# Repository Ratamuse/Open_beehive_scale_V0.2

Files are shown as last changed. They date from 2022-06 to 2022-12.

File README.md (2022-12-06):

# Open_beehive_scale_V0.2

Balance connectée autonome sur réseau LORA/LORAWAN

1/Exemple de balance en profilé alu de type Bosch Rexroth utilisable sur fond de ruche Nicot.

- 2x profilé alu 60x30mm fente 8mm de 480mm
- 4 x profilé alu 30x30mm fente 8mm de 430mm
- 1 jauge de contrainte BOSCHE H40A de 150 kg
- 24 x equerre de fixation interne profilés 8 mm

Pièces imprimées 3D

- 4 x capuchons pour profilés du bas de la balance.
- 2 x capuchons arrière pour maintenir le fond de ruche Nicot.
- 1 x capuchon gauche et 1 x capuchon droit pour maintenir le fond de ruche Nicot.
- 2 x entretoises à placer entre les profilés 60x30 et la jauge de contrainte.
- 8 x vis tête cylindrique bombée M8x40mm
- 4 x vis tête cylindrique bombée M8x30mm

Prévoir un taraud M5 pour fileter de chaque coté deux profilés alu 30x30mm

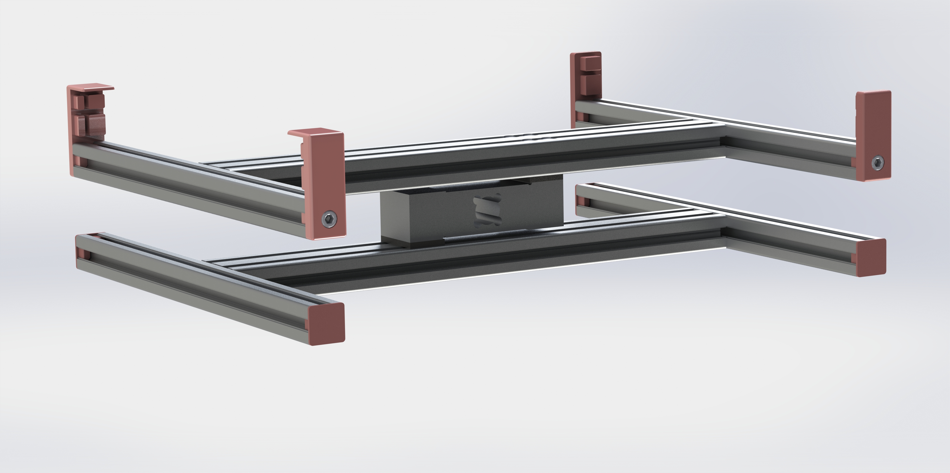
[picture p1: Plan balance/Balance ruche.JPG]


2/ Circuit imprimé dessiné autour de la carte Arduino MKRWAN 1310
- Possibilité de brancher jusqu'à:
- 4 balances (circuit HX711)
- 4 sondes externes de température/humidité SHT40
- 4 sondes de température DS1820b
- 1 broche I2C spare (possibilité de brancher par exemple un capteur de luminosité)
- 1 broche analogique ou numérique spare (possibilité de brancher par exemple un pluviomètre)
- 1 GPS QUECTEL L80-M33
- 1 batterie Lipo
- 1 panneau solaire 1W

Recharge de la batterie par un chargeur solaire MPPT. 
Surveillance de la température/humidité de la carte par un capteur SHT4X soudé sur la carte.
Jauge batterie I2C
Baromètre MS5611
Lecteur de carte SD
Capteur de mouvement (contacteur à bille) pour créer un alarme.

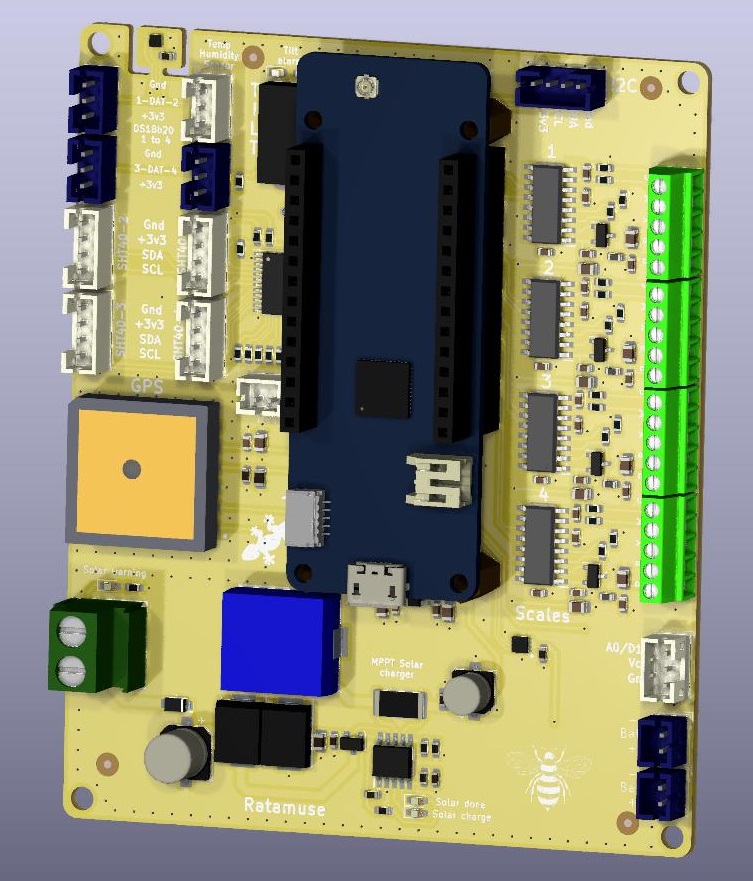
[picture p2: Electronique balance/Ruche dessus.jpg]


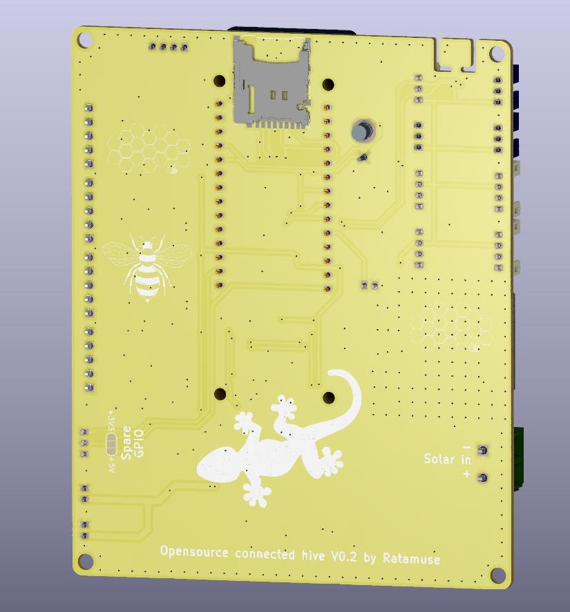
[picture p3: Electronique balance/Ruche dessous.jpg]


3/Récupération des données: 

Les données sont envoyées sur The Things Network via une passerelle Lora situé dans mon logement.
Les données sont ensuites récupérées sur un raspberry et affichées soit sur Domoticz soit sur Grafana via la création de bases de données InfluxDB et récupération des données avec NodeRed. 

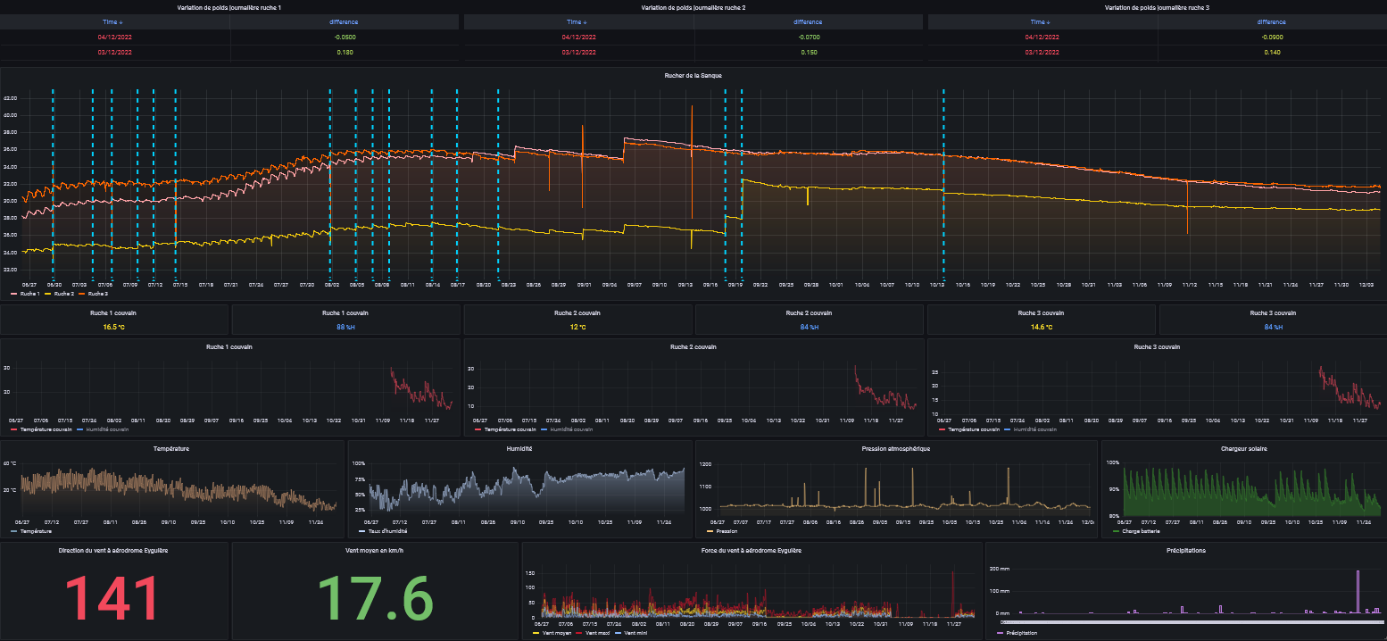
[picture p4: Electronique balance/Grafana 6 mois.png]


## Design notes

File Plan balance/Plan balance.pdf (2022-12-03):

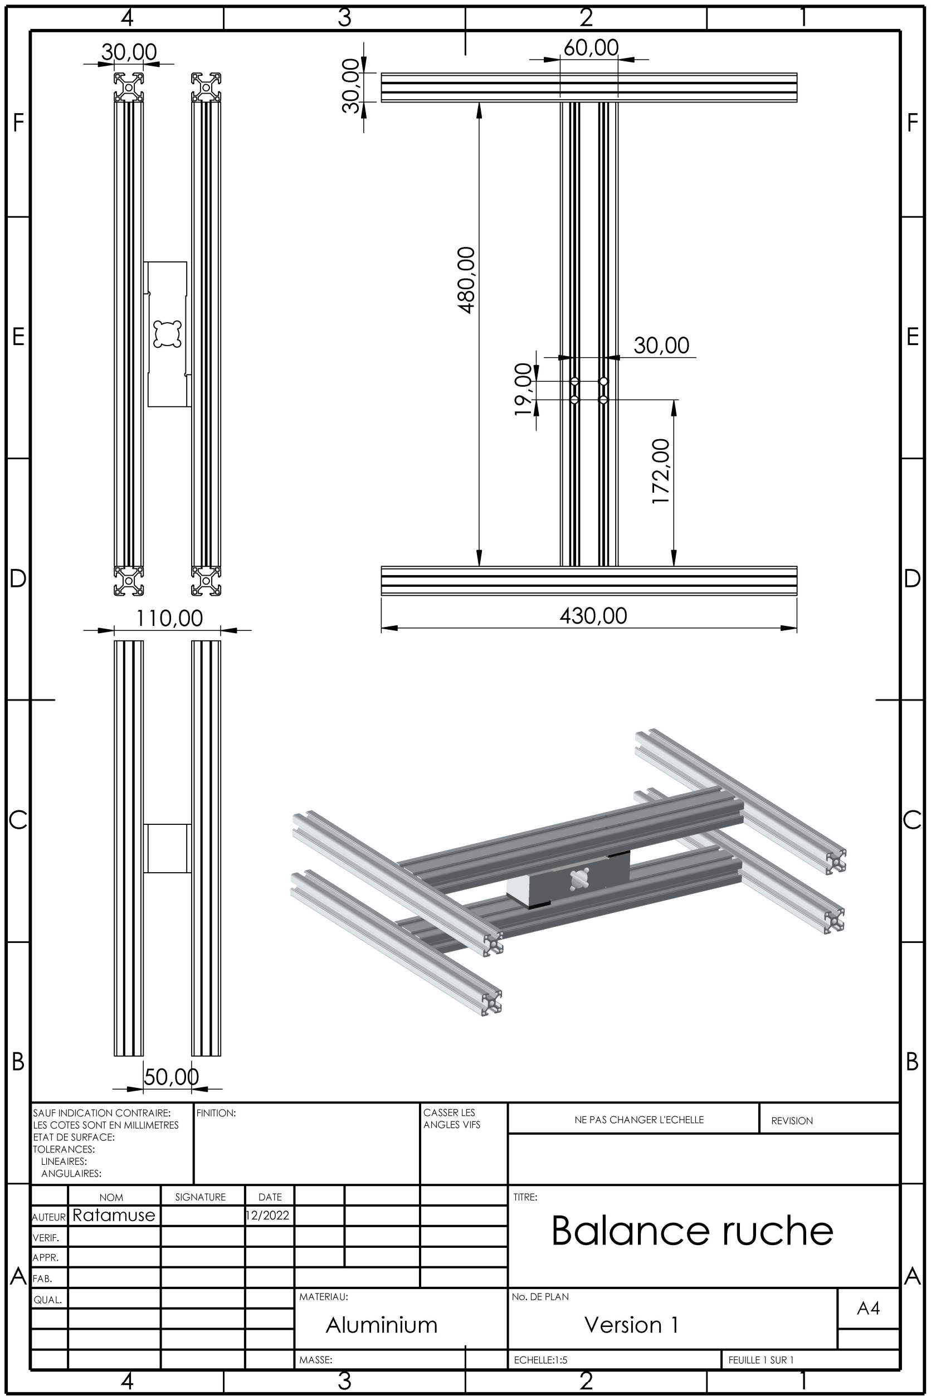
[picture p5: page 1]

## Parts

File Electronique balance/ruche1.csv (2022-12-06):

Id | Référence | Boîtier | Quantité | Désignation | Fournisseur et réf
1 | C1 | CP_Elec_6.3x7.7 | 1 | 100µF/35V
2 | C2 | C_0603_1608Metric | 1 | 470nF/50V
3 | C3 | C_0805_2012Metric | 1 | 4.7µF/50V
4 | C4 | C_0603_1608Metric | 1 | 220nF
5 | C5,C6,C20,C38,C41,C33,C29,C22,C36,C40,C48,C15,C34,C19,C28,C31,C53,C47,C26,C14,C25,C32,C43,C50,C24,C45,C10,C39,C17,C46 | C_0603_1608Metric | 30 | 0.1µF
6 | C7 | C_0603_1608Metric | 1 | 0.1µF/50V
7 | C8,C11,C18,C23,C44,C30,C35,C49,C12,C27,C42,C54,C13,C16,C37 | C_0805_2012Metric | 15 | 10µF
8 | C9 | CP_Elec_5x5.4 | 1 | 10µF
9 | D1,D3,D4 | LED_0603_1608Metric_Castellated | 3 | LED
10 | D2 | SODFL3616X98N | 1 | MBR230LSFT1G
11 | D5,D6 | DIOM8059X256N | 2 | SS34
12 | IC1 | SOP100P600X175-10N | 1 | CN3791
13 | J1 | SHDR2W90P0X500_1X2_1060X980X1380P | 1 | Conn_01x02
14 | J5,J11,J12,J17,J18 | JST_PH_B4B-PH-K_1x04_P2.00mm_Vertical | 5 | Conn_01x04
15 | L1 | INDPM138126X700N | 1 | 82µH/3A
16 | Q1 | SOT-23 | 1 | AO3401A
17 | R1 | R_0603_1608Metric | 1 | 2K
18 | R2 | R_0603_1608Metric | 1 | 120
19 | R3,R4,R7,R8,R32,R40,R38,R36,R39,R11,R34,R37,R33,R35 | R_0603_1608Metric | 14 | 10K
20 | R5 | R_0603_1608Metric | 1 | 30K
21 | R6 | R_2512_6332Metric | 1 | 0.24R
22 | J6,J7,J19 | JST_PH_B2B-PH-K_1x02_P2.00mm_Vertical | 3 | Conn_01x02
23 | IC2 | SON50P200X200X80-9N-D | 1 | MAX17048G+
24 | J8,J9,J3,J14,J4 | JST_PH_B3B-PH-K_1x03_P2.00mm_Vertical | 5 | Conn_01x03
25 | IC3 | L80-M39 | 1 | L86-M33
26 | R10 | R_0603_1608Metric | 1 | 100k
27 | S1 | RB231X2 | 1 | RB231X2
28 | R17,R29,R25,R21 | R_0603_1608Metric | 4 | 8.2K
29 | C52 | C_0805_2012Metric | 1 | 0.1µF
30 | Q5,Q3,Q4,Q2 | SOT-23 | 4 | MMBT4403
31 | C51 | C_0603_1608Metric | 1 | 10µF
32 | R16,R28,R20,R24 | R_0603_1608Metric | 4 | 20K
33 | J16,J2,J10,J15 | connecteurs5 | 4 | Conn_01x05
34 | L4,L2,L5,L3 | L_0603_1608Metric | 4 | 3.3µH
35 | D7 | LED_0603_1608Metric | 1 | LED
36 | U4 | TSSOP-24_4.4x7.8mm_P0.65mm | 1 | TCA9548APWR
37 | U5,U3 | SOT-23-5 | 2 | XC6220B331MR
38 | FB1 | R_0603_1608Metric | 1 | FerriteBead
39 | C21 | C_0805_2012Metric | 1 | 4.7µF
40 | R27,R30,R26,R22,R31,R19,R18,R23 | R_0603_1608Metric | 8 | 100
41 | IC6,IC7,IC8,IC5 | SOIC127P600X160-16N | 4 | HX711
42 | R15,R14,R13 | R_0603_1608Metric | 3 | 10k
43 | U1 | ARDUINO_ABX00012 | 1 | MKRWAN_1310
44 | G*** | Logo Ratamuse petit | 1 | LOGO
45 | FID4,FID1,FID2,FID3 | Fiducial_1mm_Mask3mm | 4 | Fiducial
46 | IC4 | SHT41AD1BR3 | 1 | SHT41-AD1B-R3
47 | R9 | R_0603_1608Metric | 1 | 4.7K
48 | U2 | LGA-8_3x5mm_P1.25mm | 1 | MS5611-01BA
49 | JP1 | SolderJumper-3_P1.3mm_Open_RoundedPad1.0x1.5mm_NumberLabels | 1 | SolderJumper_3_Open
50 | J13 | microSD_HC_Hirose_DM3AT-SF-PEJM5 | 1 | Micro_SD_Card
51 | G*** | Logo Ratamuse | 1 | LOGO

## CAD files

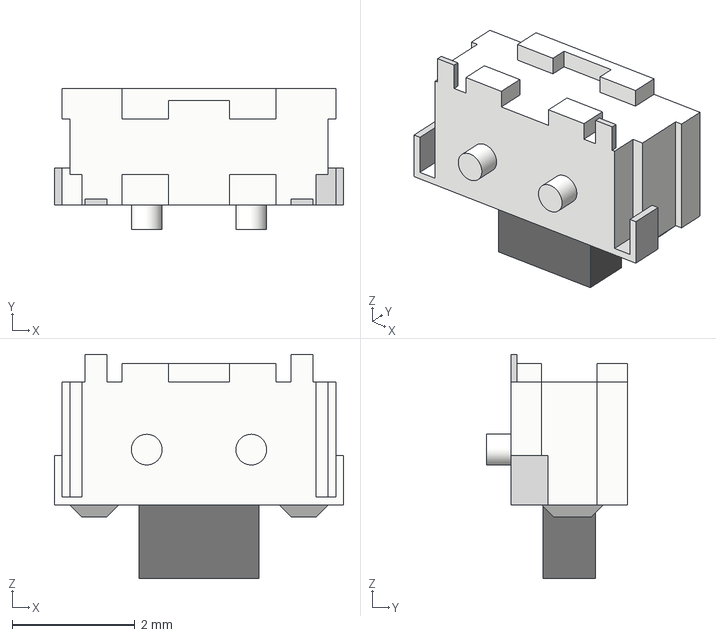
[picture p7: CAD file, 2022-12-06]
Electronique balance/3D/1TS003B.step
4.70 x 2.30 x 3.65 mm

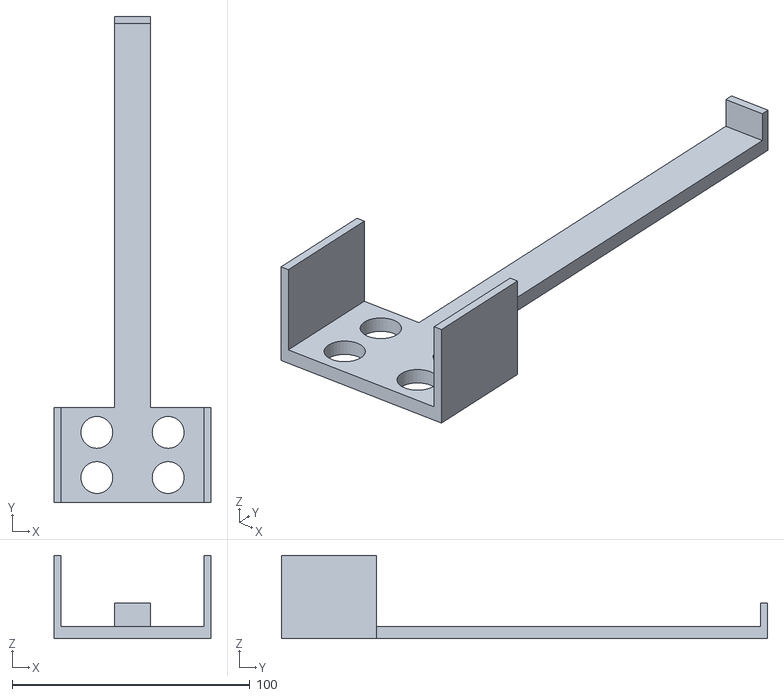
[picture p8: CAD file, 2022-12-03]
Plan balance/gabarit percage ruche13.STL
66.0 x 204.5 x 35.0

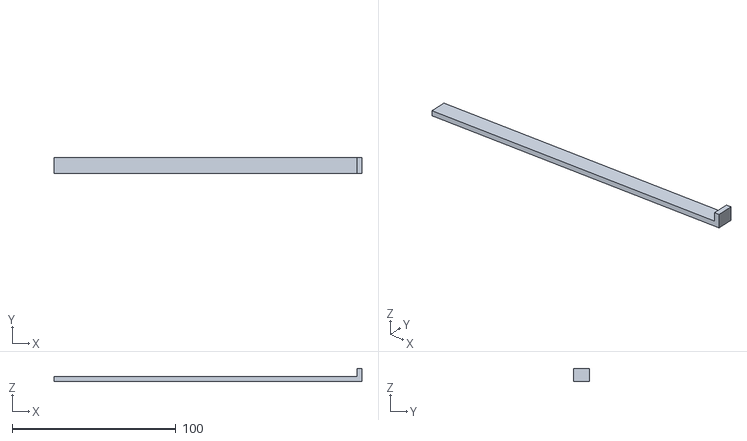
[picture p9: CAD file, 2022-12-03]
Plan balance/gabari placement bras balance.STL
188.0 x 10.0 x 8.00

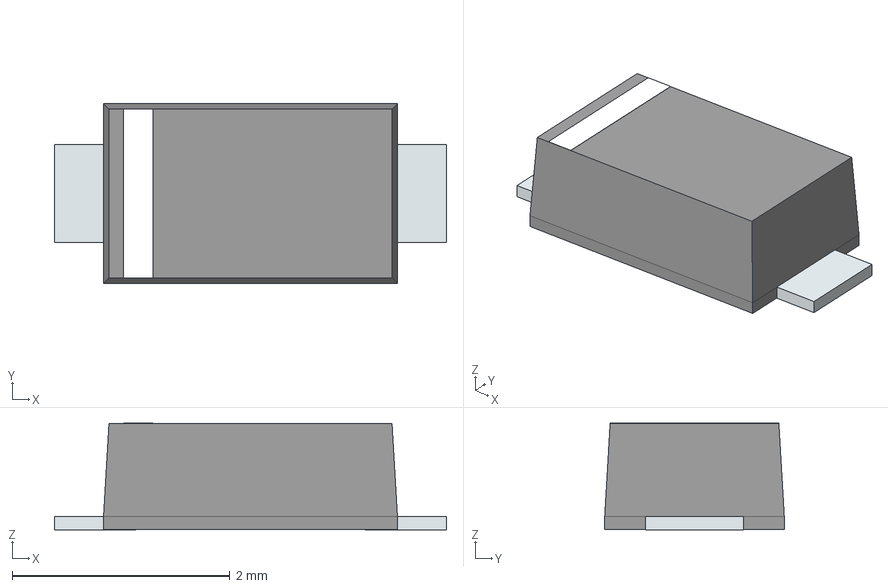
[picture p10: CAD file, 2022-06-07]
Electronique balance/3D/MBR230LSFT1G.stp
3.60 x 1.65 x 0.98 mm
PinKIdent
PinK
PinA

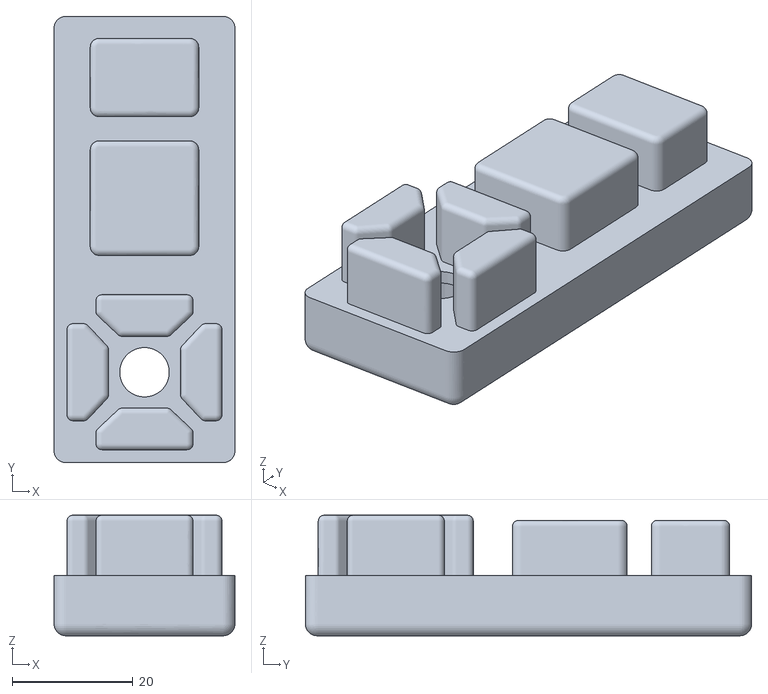
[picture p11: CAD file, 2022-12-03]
Plan balance/Fixation plancher Nicot AR.STL
30.0 x 74.0 x 20.0

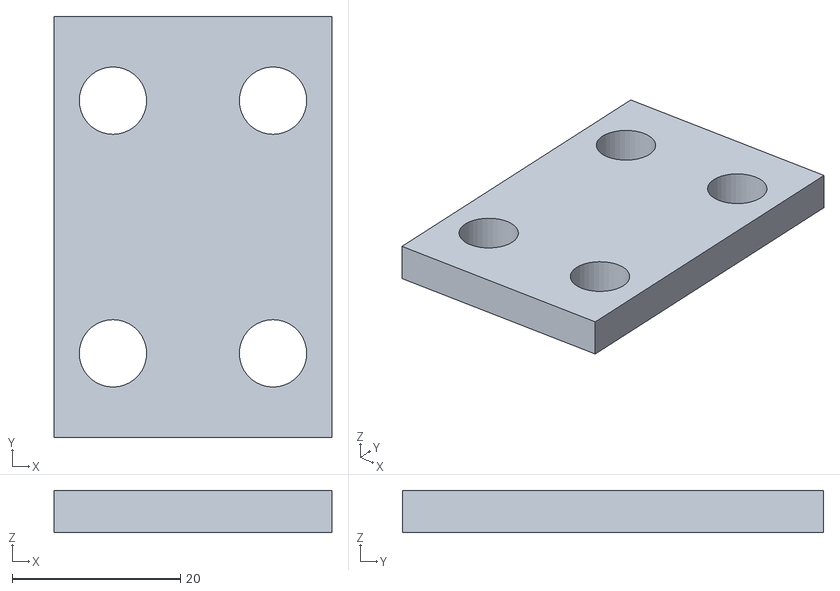
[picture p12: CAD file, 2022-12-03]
Plan balance/Entretoise balance.STL
33.0 x 50.0 x 5.00

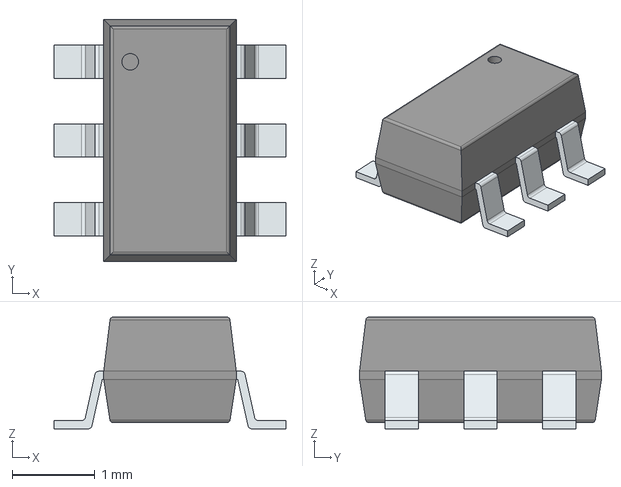
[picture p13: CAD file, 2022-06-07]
Electronique balance/3D/DW01.stp
2.80 x 2.92 x 1.35 mm
PinsArrayLR

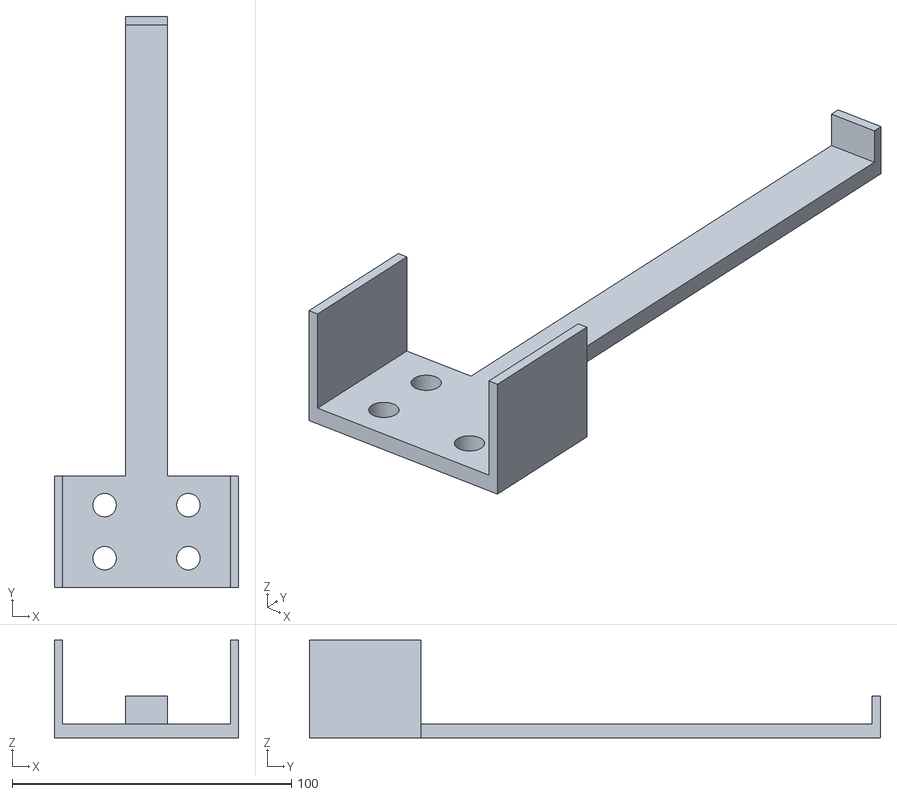
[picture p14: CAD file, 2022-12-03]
Plan balance/gabarit percage ruche.STL
66.0 x 204.5 x 35.0

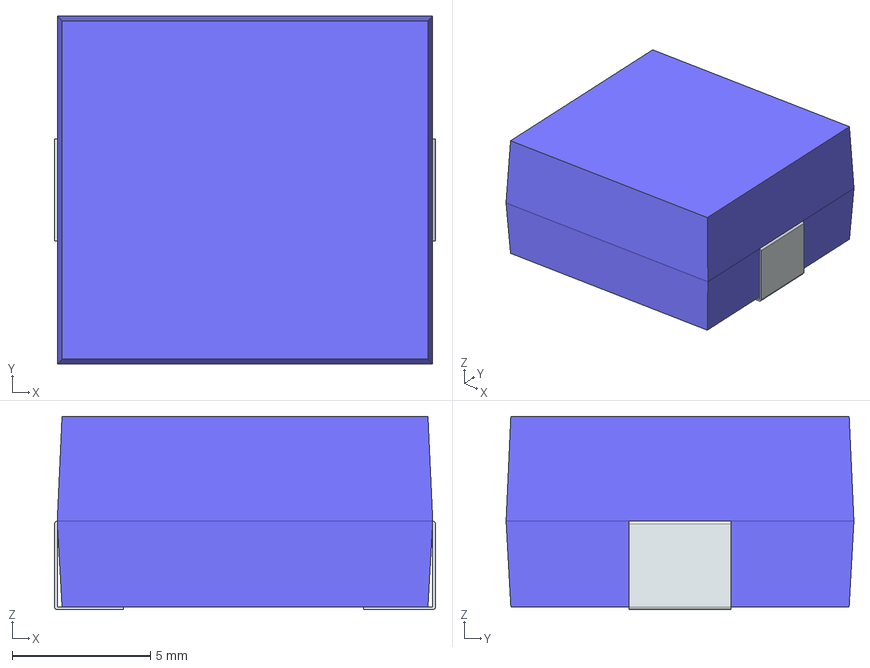
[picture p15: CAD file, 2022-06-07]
Electronique balance/3D/SMMS1360-220M.stp
13.8 x 12.6 x 7.00 mm
FilletPin1
FilletPin2

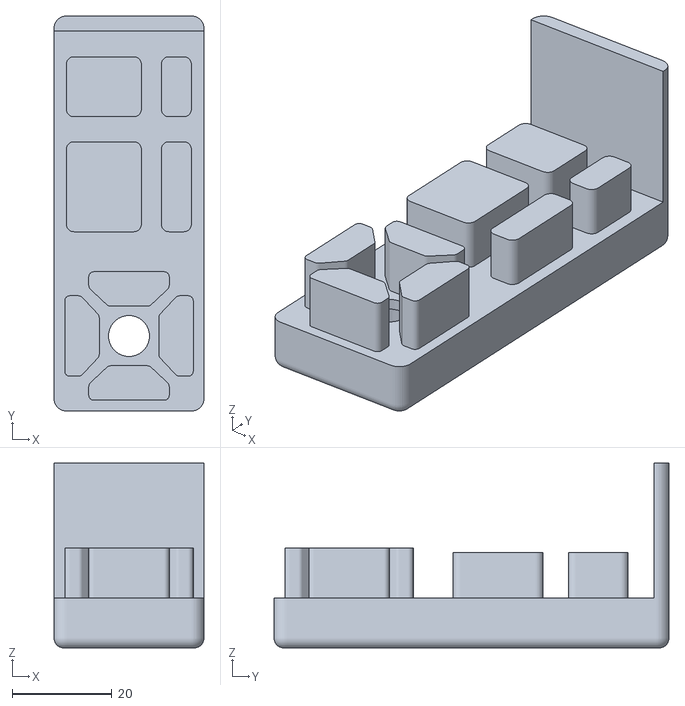
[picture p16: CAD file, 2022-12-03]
Plan balance/Fixation plancher Nicot AV G.STL
30.0 x 79.0 x 37.0

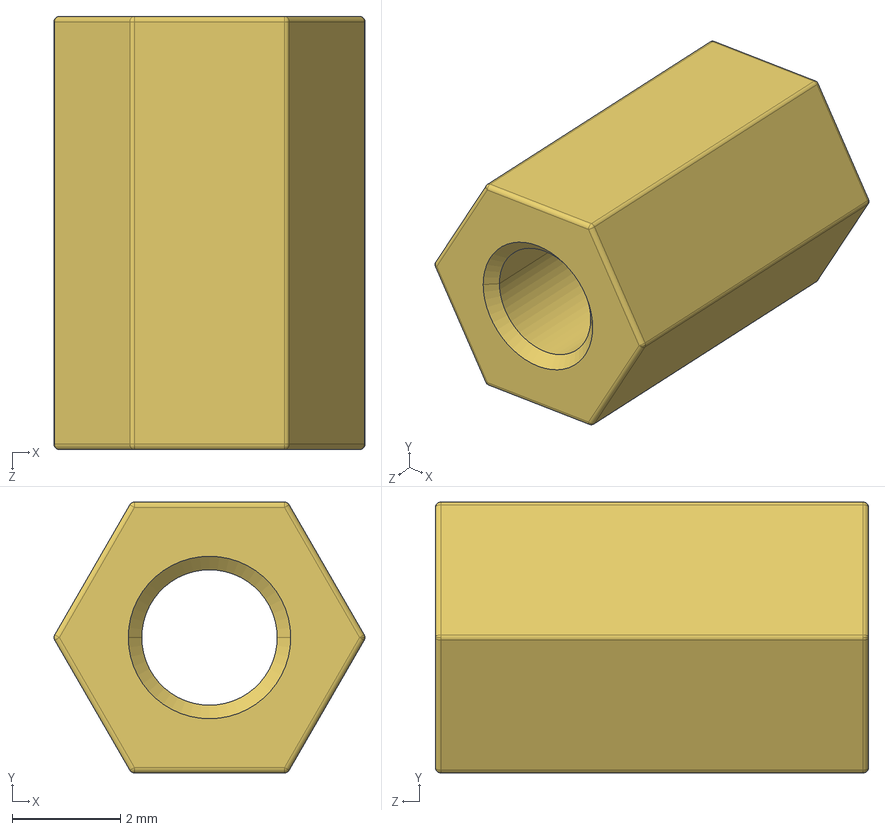
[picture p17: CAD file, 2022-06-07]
Electronique balance/3D/HTSB-M3-8-5-1.STEP
5.74 x 5.00 x 8.00 mm

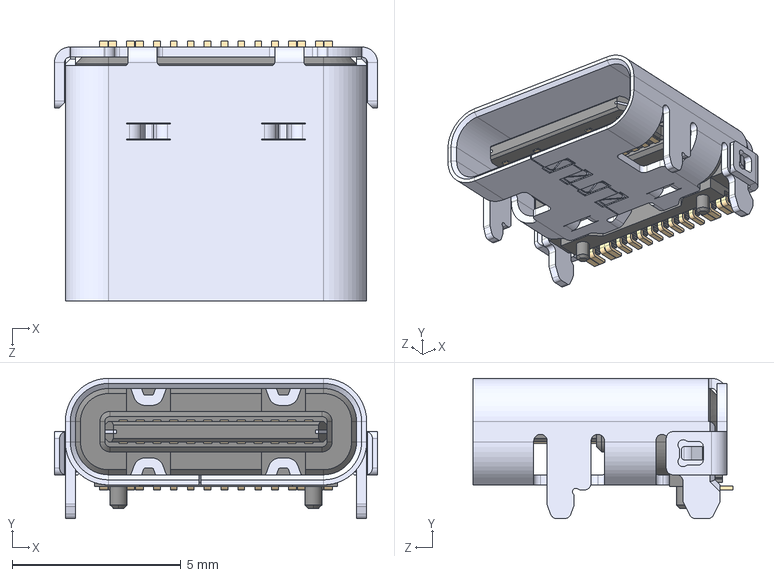
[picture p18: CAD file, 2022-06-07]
Electronique balance/3D/USB4105-GF-A--3DModel-STEP-56544.STEP
9.58 x 4.16 x 7.71 mm

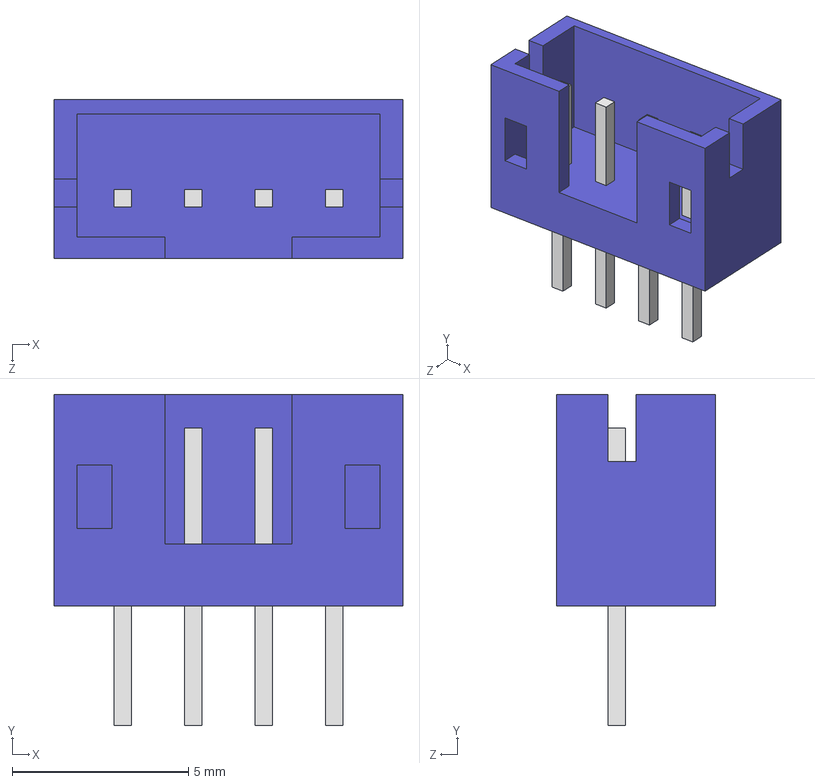
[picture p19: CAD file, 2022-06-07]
Electronique balance/3D/B4B-PH-K-S.STEP
9.90 x 9.40 x 4.50 mm

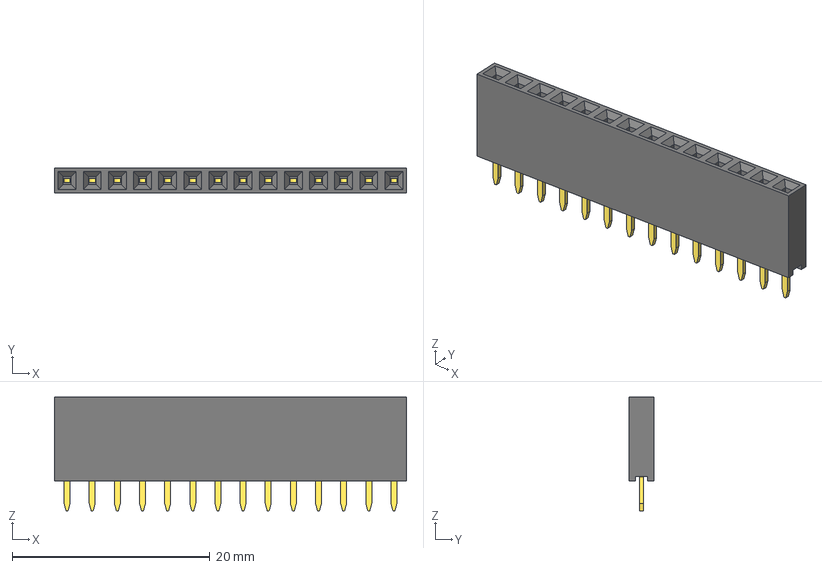
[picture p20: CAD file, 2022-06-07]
Electronique balance/3D/PBS-14.step
35.6 x 2.54 x 11.5 mm

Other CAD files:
Plan balance/Fixation plancher Nicot AV D.STL
Electronique balance/3D/AO3400.stp
Electronique balance/3D/FS8205.stp
Electronique balance/3D/MMBT4403.stp
Electronique balance/3D/1050170001.stp
Electronique balance/3D/12BHC186P1-GR.stp
Electronique balance/3D/1546215-2.stp
Electronique balance/3D/39700-0205.stp
Electronique balance/3D/691216710002.stp
Electronique balance/3D/B2B-PH-K-S.STEP
Electronique balance/3D/B3B-PH-K-S.STEP
Electronique balance/3D/B3S_100[].step
Electronique balance/3D/B4B-PH-SM4-TB.STEP
Electronique balance/3D/BME680.step
Electronique balance/3D/CN3791.stp
Electronique balance/3D/ESP32-WROOM-32E_M113EH2800PH3Q0_.stp
Electronique balance/3D/FS312F-G.stp
Electronique balance/3D/FS8205A.stp
Electronique balance/3D/HTSB-M3-12-5-1.STEP
Electronique balance/3D/HTSB-M3-8-5,5-1.STEP
Electronique balance/3D/HX711.stp
Electronique balance/3D/L86.step
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

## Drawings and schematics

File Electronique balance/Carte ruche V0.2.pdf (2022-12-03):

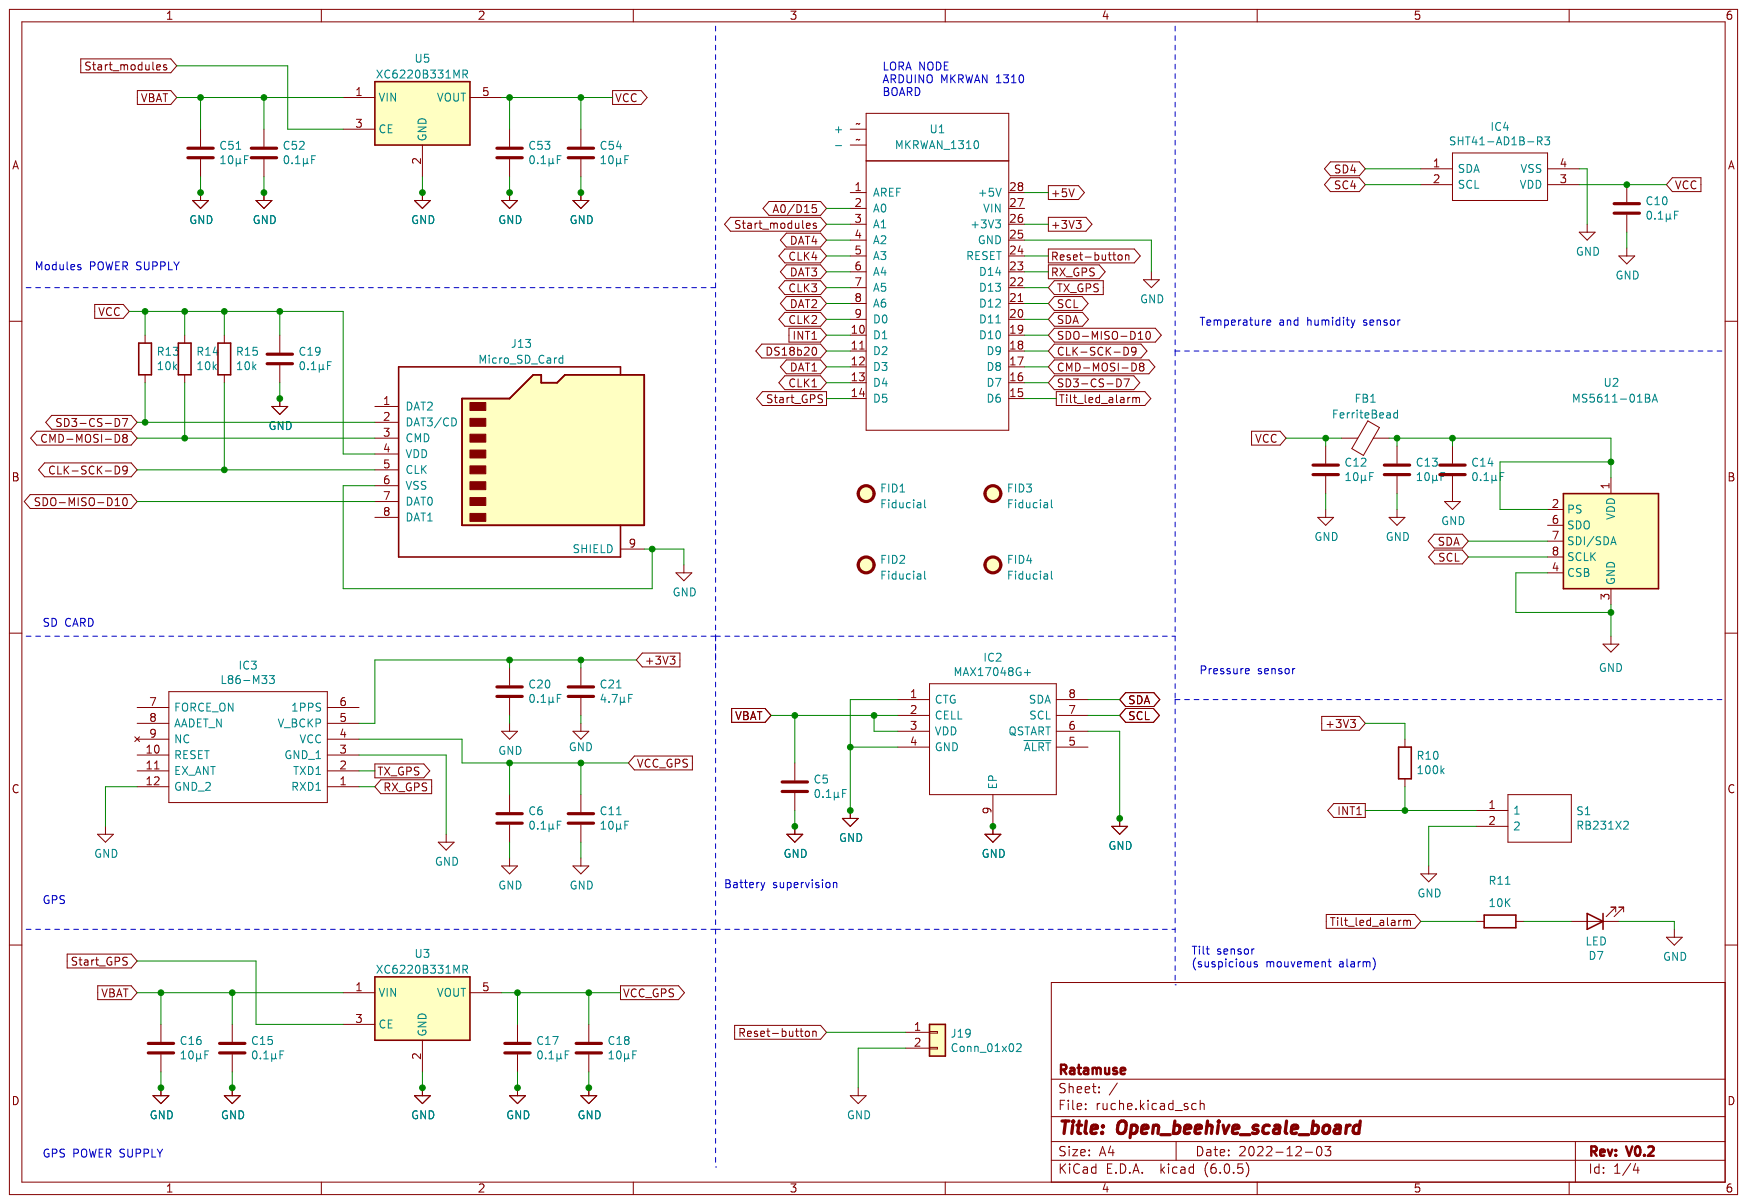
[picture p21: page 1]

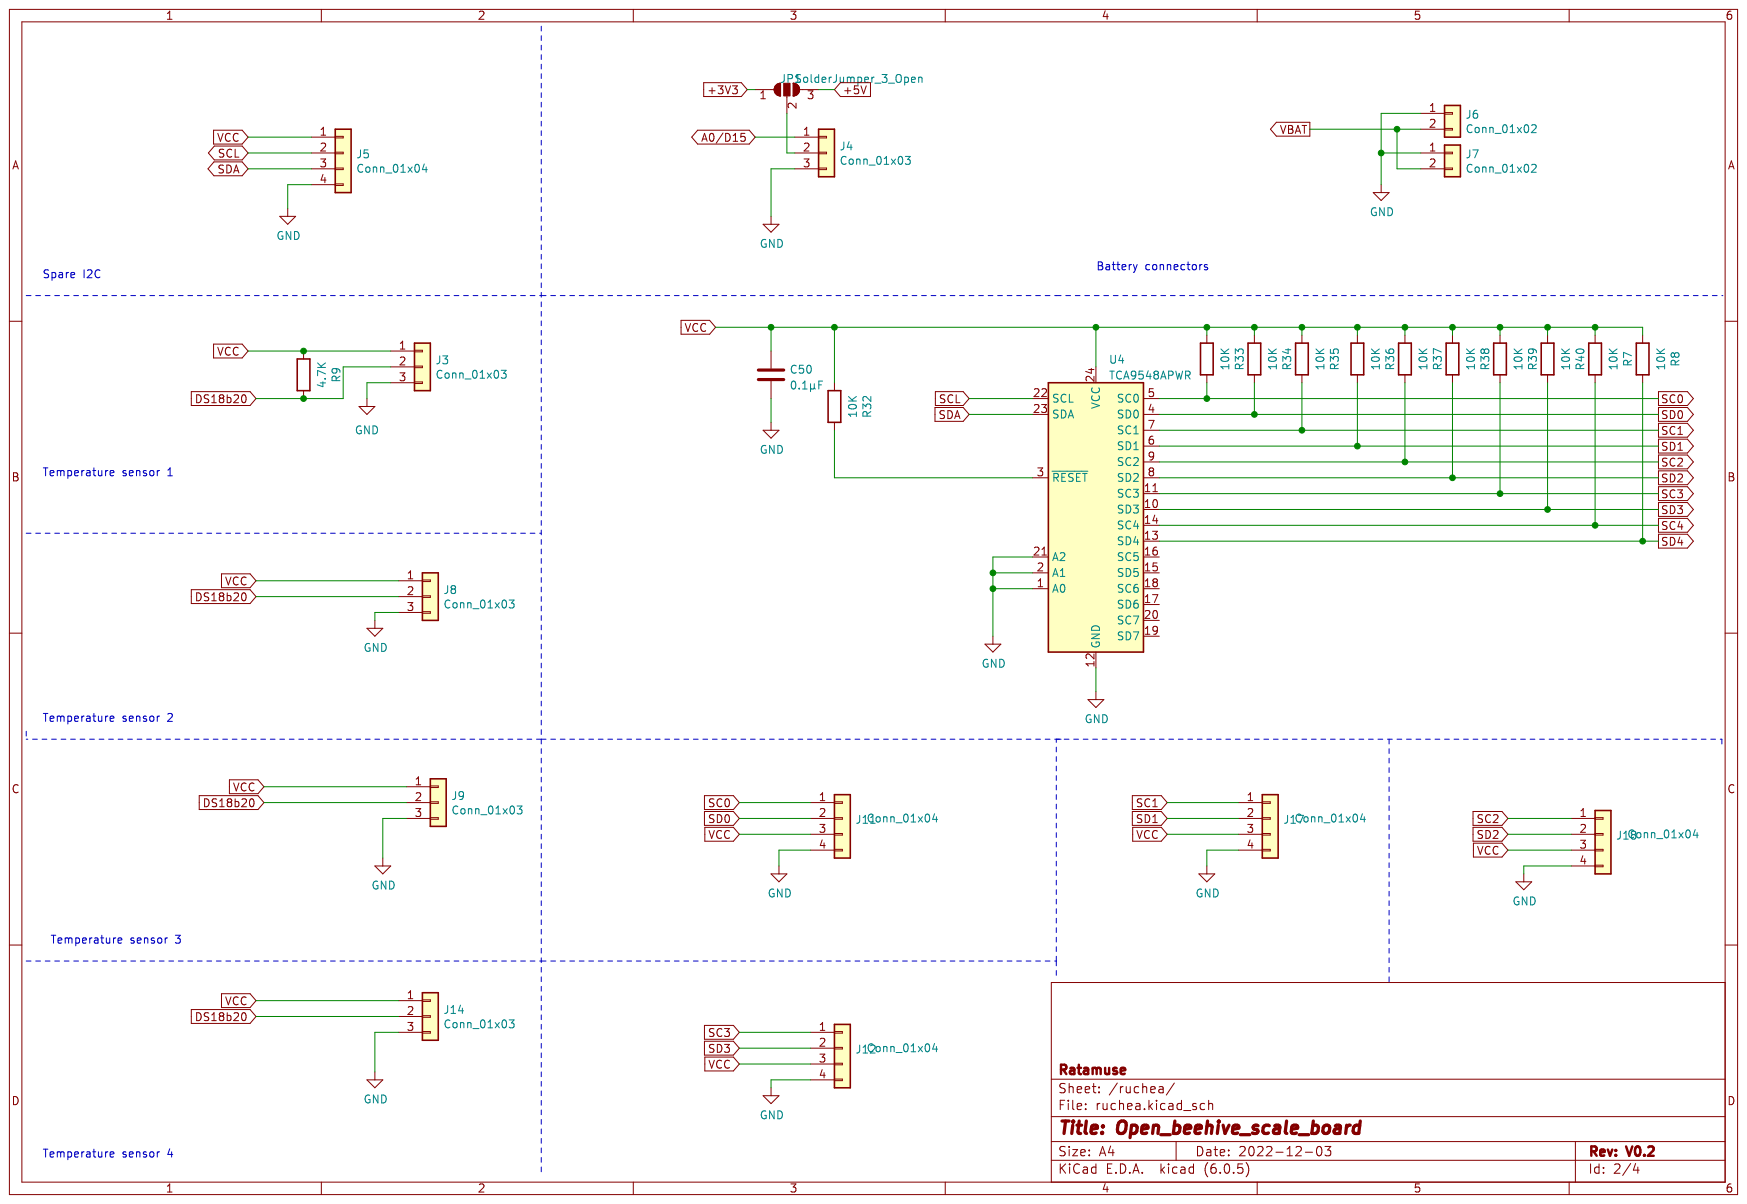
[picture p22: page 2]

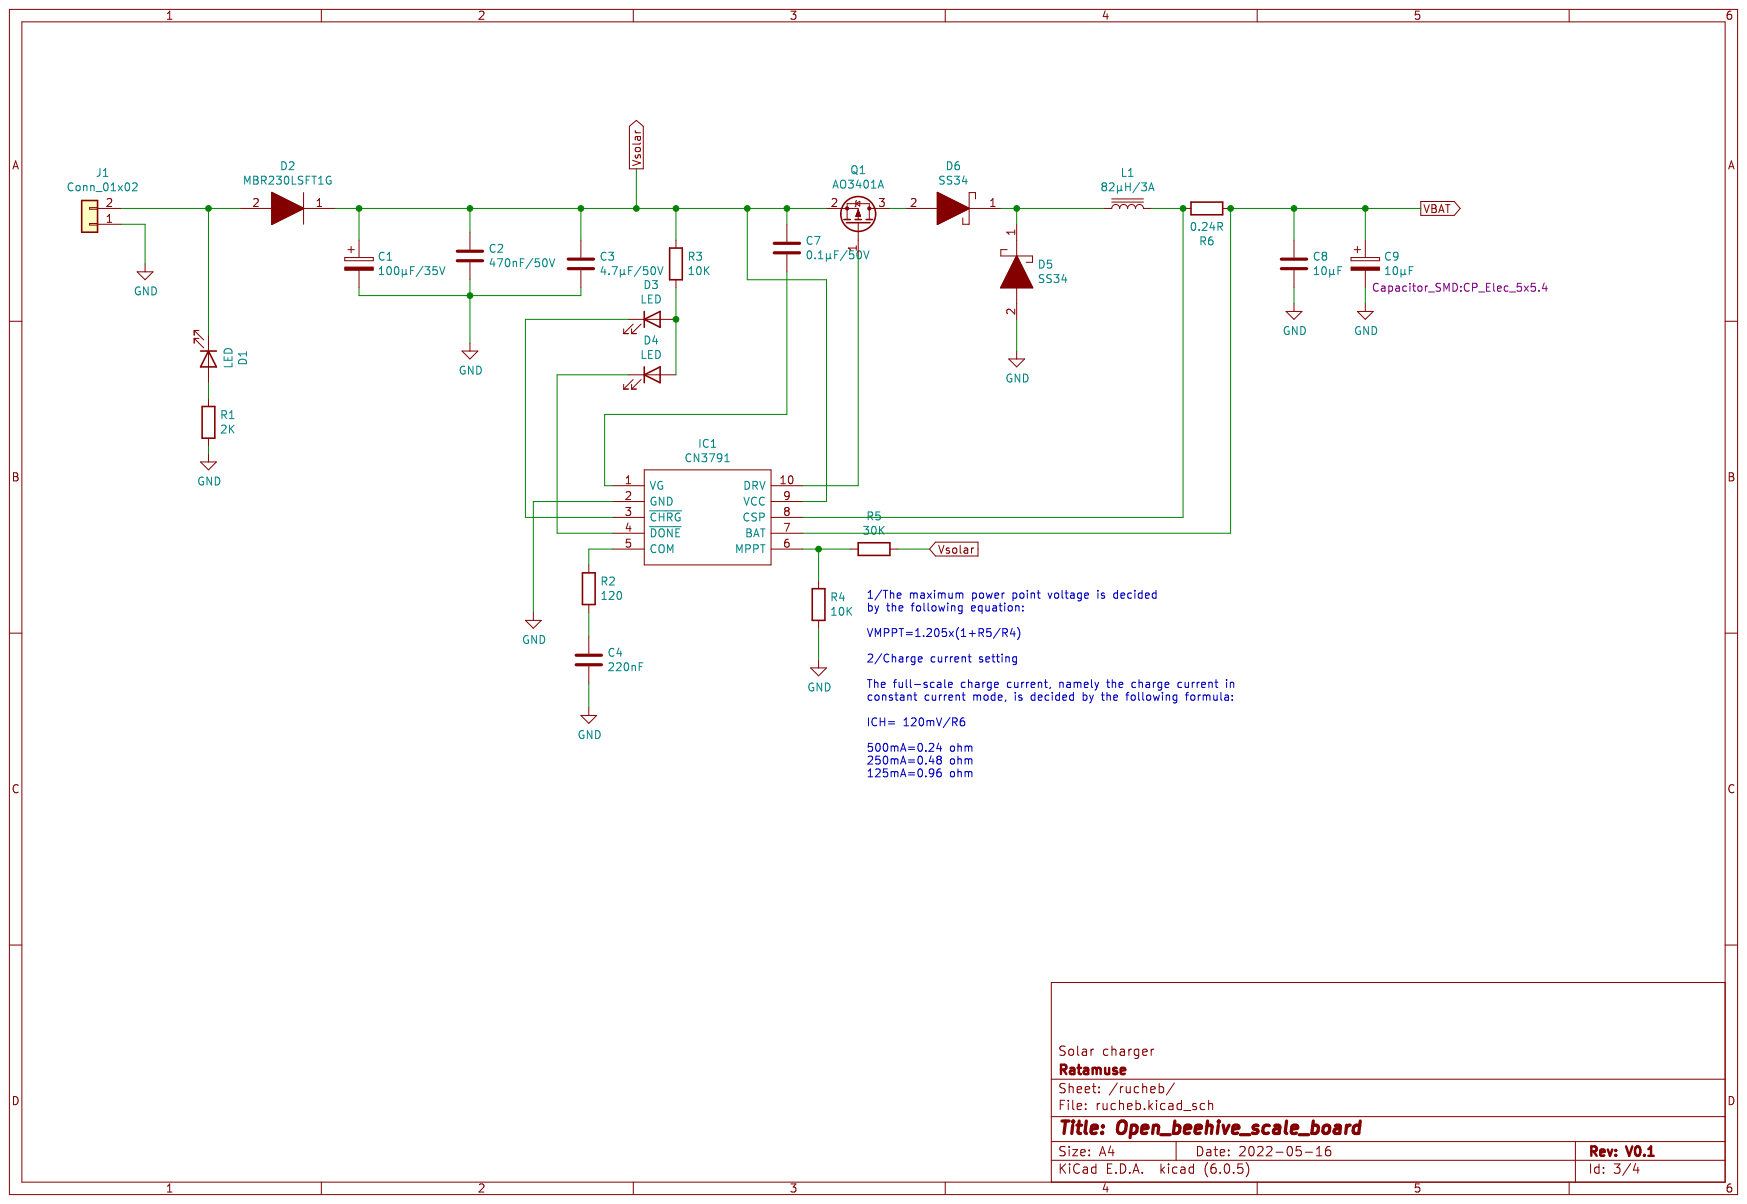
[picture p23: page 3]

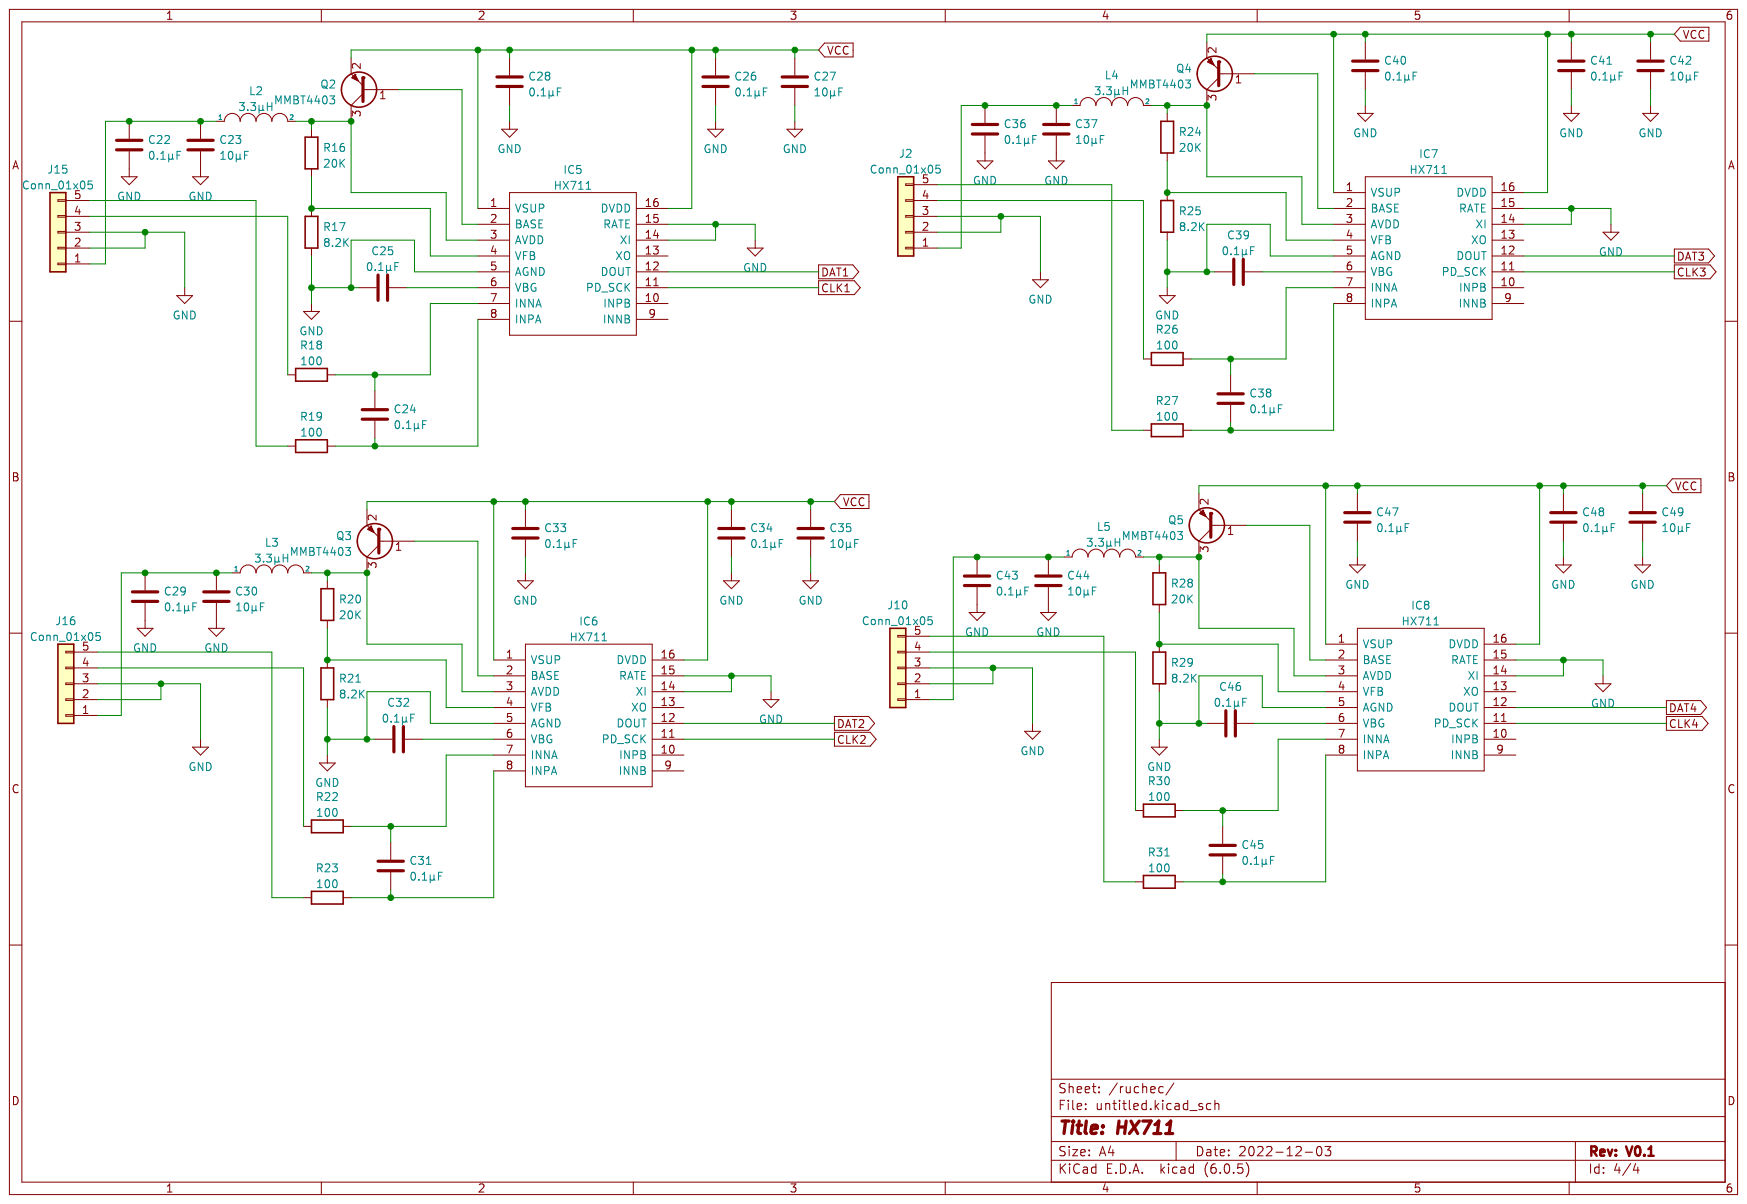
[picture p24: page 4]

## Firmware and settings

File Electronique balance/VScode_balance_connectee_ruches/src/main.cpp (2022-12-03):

#include <MKRWAN.h>           // LoRaWAN Library
#include <CayenneLPP.h>       // CAYENNE LPP
#include "ArduinoLowPower.h"  // Low Power Library




#define FRAME_DELAY       300000
#define DATA_RATE         5
#define ADAPTIVE_DR       true
#define CONFIRMED         false
#define PORT              2
#define CAYENNE_LPP       true
#define LOW_POWER         false
#define DEBUG
//#undef DEBUG

void getWeightscale1();
void getWeightscale2();
void getWeightscale3();
void Max17048();
void SHT4x();
void sendLoRa();
void enterLowPower();




/**** LoRaWAN Setup ******/
LoRaModem modem;
String appEui = "0000000000000000"; 
//String appKey = "xxxxxxxxxxxxxxxxxxxxxx";   // Ruche 1
String appKey = ""xxxxxxxxxxxxxxxxxxxxxx"";   // Ruche 2
uint8_t dataToSend[20] = {0}; // Data to send
uint8_t dataReceived[20] = {0}; // Data received via Donwlink
uint32_t frameDelay = FRAME_DELAY;

CayenneLPP dataToSendCayenne(51);
CayenneLPP dataReceivedCayenne(51);


/*********HX711***************/

#include "HX711.h"


// HX711 circuit wiring
const int LOADCELL_DOUT_PIN1 = 4;
const int LOADCELL_SCK_PIN1 = 3;
const int LOADCELL_DOUT_PIN2 = 18;
const int LOADCELL_SCK_PIN2 = 17;
const int LOADCELL_DOUT_PIN3 = 20;
const int LOADCELL_SCK_PIN3 = 19;

HX711 scale1;
HX711 scale2;
HX711 scale3;

#define number1
void HT711_1(number1);

#define number2
void HT711_2(number2);

#define number3
void HT711_3(number3);

/***************************************DS18B20*********************************/

// Include the libraries we need
#include <OneWire.h>
#include <DallasTemperature.h>

// Data wire is plugged into port 13 on the Arduino
#define ONE_WIRE_BUS 13

// Setup a oneWire instance to communicate with any OneWire devices (not just Maxim/Dallas temperature ICs)
OneWire oneWire(ONE_WIRE_BUS);

// Pass our oneWire reference to Dallas Temperature. 
DallasTemperature sensors(&oneWire);

/*The setup function. We only start the sensors here*/
int deviceCount = 0;
float tempC;

/*************************MAX17048****************************************/

#include <Wire.h> // Needed for I2C
#include <SparkFun_MAX1704x_Fuel_Gauge_Arduino_Library.h> // Click here to get the library: http://librarymanager/All#SparkFun_MAX1704x_Fuel_Gauge_Arduino_Library

//SFE_MAX1704X lipo; // Defaults to the MAX17043

//SFE_MAX1704X lipo(MAX1704X_MAX17043); // Create a MAX17043
//SFE_MAX1704X lipo(MAX1704X_MAX17044); // Create a MAX17044
SFE_MAX1704X lipo(MAX1704X_MAX17048); // Create a MAX17048
//SFE_MAX1704X lipo(MAX1704X_MAX17049); // Create a MAX17049

double voltage = 0; // Variable to keep track of LiPo voltage
double soc = 0; // Variable to keep track of LiPo state-of-charge (SOC)
bool alert; // Variable to keep track of whether alert has been triggered

/********************************SHT4X******************************/

#include <Arduino.h>
#include <SensirionI2CSht4x.h>
SensirionI2CSht4x sht4x;

 
void setup() {
  int connected;
  
  /***** Serial Link Configuration ******/
  Serial.begin(115200);
  //while (!Serial);
  pinMode(LED_BUILTIN, OUTPUT);
  for(uint32_t i=0;i<10;i++){
      digitalWrite(LED_BUILTIN, HIGH);
      delay(200);
      digitalWrite(LED_BUILTIN, LOW);
      delay(200);
  }
  Serial.println("\r\n\r\n\r\n");
  Serial.println("########################################");
  Serial.println("########   LoRaWAN MKRWAN Scale   ######");
  Serial.println("#########     OTAA activation   ########\r\n");

  /****** Configure Here the First Module *****/
  //Enter here module configuration, ie : temperature sensor

   /****** Configure Here the Second Module *****/
  //Enter here module configuration, ie : Weight scale
  
  /**** LoRaWAN Configuration *****/
  if (!modem.begin(EU868)) {
    Serial.println("Failed to start module");
    while (1);
    Serial.print("Your device EUI is: ");
    Serial.println(modem.deviceEUI());
  };
  
  do{
  Serial.println(" JOIN procedure in progress ...");  
  connected = modem.joinOTAA(appEui, appKey);
  if (!connected)   Serial.println(" JOIN OTAA failed!!! Retry...");
  else              Serial.println(" JOIN procedure : SUCCESS !\r\n");
  }while(!connected);
  modem.dataRate(DATA_RATE);
  modem.setADR(1);
  modem.setPort(PORT);
  Serial.print(" Frame will be sent every ");Serial.print((frameDelay<7000)?7000:frameDelay);Serial.println("ms\r\n");  

/******************* DS18B20 ****************************/
  sensors.begin();
sensors.requestTemperatures(); // Send the command to get temperatures
deviceCount = sensors.getDeviceCount();
  Serial.print(deviceCount, DEC);
  Serial.println(" devices.");
  Serial.println("");

/*********HX711-1***************/

Serial.println("HX711-1 Demo");

  Serial.println("Initializing the scale");

  // Initialize library with data output pin, clock input pin and gain factor.
  // Channel selection is made by passing the appropriate gain:
  // - With a gain factor of 64 or 128, channel A is selected
  // - With a gain factor of 32, channel B is selected
  // By omitting the gain factor parameter, the library
  // default "128" (Channel A) is used here.
  scale1.begin(LOADCELL_DOUT_PIN1, LOADCELL_SCK_PIN1);

  Serial.println("Before setting up the scale:");
  Serial.print("read: \t\t");
  Serial.println(scale1.read());      // print a raw reading from the ADC

  Serial.print("read average: \t\t");
  Serial.println(scale1.read_average(20));   // print the average of 20 readings from the ADC

  Serial.print("get value: \t\t");
  Serial.println(scale1.get_value(5));   // print the average of 5 readings from the ADC minus the tare weight (not set yet)

  Serial.print("get units: \t\t");
  Serial.println(scale1.get_units(5), 1);  // print the average of 5 readings from the ADC minus tare weight (not set) divided
            // by the SCALE parameter (not set yet)

  scale1.set_scale(30556);                      // this value is obtained by calibrating the scale with known weights; see the README for details
  //scale.tare();               // reset the scale to 0

  Serial.println("After setting up the scale:");

  Serial.print("read: \t\t");
  Serial.println(scale1.read());                 // print a raw reading from the ADC

  Serial.print("read average: \t\t");
  Serial.println(scale1.read_average(20));       // print the average of 20 readings from the ADC

  Serial.print("get value: \t\t");
  Serial.println(scale1.get_value(5));   // print the average of 5 readings from the ADC minus the tare weight, set with tare()

  Serial.print("get units: \t\t");
  Serial.println(scale1.get_units(5), 2);        // print the average of 5 readings from the ADC minus tare weight, divided
            // by the SCALE parameter set with set_scale

  Serial.println("Readings:");

/*********HX711-2***************/

Serial.println("HX711-2 Demo");

  Serial.println("Initializing the scale");

  // Initialize library with data output pin, clock input pin and gain factor.
  // Channel selection is made by passing the appropriate gain:
  // - With a gain factor of 64 or 128, channel A is selected
  // - With a gain factor of 32, channel B is selected
  // By omitting the gain factor parameter, the library
  // default "128" (Channel A) is used here.
  scale2.begin(LOADCELL_DOUT_PIN2, LOADCELL_SCK_PIN2);

  Serial.println("Before setting up the scale:");
  Serial.print("read: \t\t");
  Serial.println(scale2.read());      // print a raw reading from the ADC

  Serial.print("read average: \t\t");
  Serial.println(scale2.read_average(20));   // print the average of 20 readings from the ADC

  Serial.print("get value: \t\t");
  Serial.println(scale2.get_value(5));   // print the average of 5 readings from the ADC minus the tare weight (not set yet)

  Serial.print("get units: \t\t");
  Serial.println(scale2.get_units(5), 1);  // print the average of 5 readings from the ADC minus tare weight (not set) divided
            // by the SCALE parameter (not set yet)

  scale2.set_scale(29323);                      // this value is obtained by calibrating the scale with known weights; see the README for details
  //scale.tare();               // reset the scale to 0

  Serial.println("After setting up the scale:");

  Serial.print("read: \t\t");
  Serial.println(scale2.read());                 // print a raw reading from the ADC

  Serial.print("read average: \t\t");
  Serial.println(scale2.read_average(20));       // print the average of 20 readings from the ADC

  Serial.print("get value: \t\t");
  Serial.println(scale2.get_value(5));   // print the average of 5 readings from the ADC minus the tare weight, set with tare()

  Serial.print("get units: \t\t");
  Serial.println(scale2.get_units(5), 2);        // print the average of 5 readings from the ADC minus tare weight, divided
            // by the SCALE parameter set with set_scale

  Serial.println("Readings:"); 


/*********HX711-3***************/

Serial.println("HX711-3 Demo");

  Serial.println("Initializing the scale");

  // Initialize library with data output pin, clock input pin and gain factor.
  // Channel selection is made by passing the appropriate gain:
  // - With a gain factor of 64 or 128, channel A is selected
  // - With a gain factor of 32, channel B is selected
  // By omitting the gain factor parameter, the library
  // default "128" (Channel A) is used here.
  scale3.begin(LOADCELL_DOUT_PIN3, LOADCELL_SCK_PIN3);

  Serial.println("Before setting up the scale:");
  Serial.print("read: \t\t");
  Serial.println(scale3.read());      // print a raw reading from the ADC

  Serial.print("read average: \t\t");
  Serial.println(scale3.read_average(20));   // print the average of 20 readings from the ADC

  Serial.print("get value: \t\t");
  Serial.println(scale3.get_value(5));   // print the average of 5 readings from the ADC minus the tare weight (not set yet)

  Serial.print("get units: \t\t");
  Serial.println(scale3.get_units(5), 1);  // print the average of 5 readings from the ADC minus tare weight (not set) divided
            // by the SCALE parameter (not set yet)

  scale3.set_scale(29508);                      // this value is obtained by calibrating the scale with known weights; see the README for details
  //scale.tare();               // reset the scale to 0

  Serial.println("After setting up the scale:");

  Serial.print("read: \t\t");
  Serial.println(scale3.read());                 // print a raw reading from the ADC

  Serial.print("read average: \t\t");
  Serial.println(scale3.read_average(20));       // print the average of 20 readings from the ADC

  Serial.print("get value: \t\t");
  Serial.println(scale3.get_value(5));   // print the average of 5 readings from the ADC minus the tare weight, set with tare()

  Serial.print("get units: \t\t");
  Serial.println(scale3.get_units(5), 2);        // print the average of 5 readings from the ADC minus tare weight, divided
            // by the SCALE parameter set with set_scale

  Serial.println("Readings:"); 

/*************************MAX17048****************************************/

Wire.begin();

  lipo.enableDebugging(); // Uncomment this line to enable helpful debug messages on Serial

  // Set up the MAX17043 LiPo fuel gauge:
  if (lipo.begin() == false) // Connect to the MAX17043 using the default wire port
  {
    Serial.println(F("MAX17043 not detected. Please check wiring. Freezing."));
    while (1)
      ;
  }

  // Quick start restarts the MAX17043 in hopes of getting a more accurate
  // guess for the SOC.
  lipo.quickStart();

  // We can set an interrupt to alert when the battery SoC gets too low.
  // We can alert at anywhere between 1% - 32%:
  lipo.setThreshold(20); // Set alert threshold to 20%.



/********************************SHT4X******************************/

uint16_t error;
    char errorMessage[256];

    sht4x.begin(Wire);

    uint32_t serialNumber;
    error = sht4x.serialNumber(serialNumber);
    if (error) {
        Serial.print("Error trying to execute serialNumber(): ");
        errorToString(error, errorMessage, 256);
        Serial.println(errorMessage);
    } else {
        Serial.print("Serial Number: ");
        Serial.println(serialNumber);
    }

}

void loop() {
  // Call here the first Module ie : getTemperature();
//DS18B20_1();
  // Call here the seconde Module ie : getWeight();
getWeightscale1();
  // Etc ...
delay(100);
getWeightscale2();
delay(100);
getWeightscale3();
delay(100);
Max17048();
delay(100);
SHT4x();
delay(100);  
sendLoRa();
delay(100);
 // if(LOW_POWER == true)   
enterLowPower();
 // else     
 //wait();

}


void sendLoRa(){
  int status;
  int i = 0;

  /***** Send data *****/
  if(CONFIRMED)   Serial.print(" Uplink CONFIRMED on PORT ");
  else            Serial.print(" Uplink UNCONFIRMED on PORT ");
  Serial.println(PORT);
  Serial.println(" Sending CAYENNE LPP (Low Power Payload) ");
  modem.beginPacket();
  //modem.write(dataToSend,1);
  modem.write(dataToSendCayenne.getBuffer(),dataToSendCayenne.getSize());
  status = modem.endPacket(CONFIRMED);
  if (status < 0) {
    Serial.println(" Send Frame failed!!!");
  } else {
    Serial.println(" Frame sent. Waiting for Downlink...");
  } 
  delay(3000); // Wait for downlink

 
  /***** Receive data *****/
  if (!modem.available()) {
    Serial.println(" No data received");
  }
  else {
    while (modem.available()) {
      dataReceived[i++] = (char)modem.read();
    }
    Serial.print(" Received Downlink (Hexa) : ");
    for (unsigned int j = 0; j < i; j++) {
      Serial.print(dataReceived[j] >> 4, HEX);
      Serial.print(dataReceived[j] & 0xF, HEX);
      Serial.print(" ");
    }  
    Serial.println();
  // First byte is the time between 2 Uplink in seconds
  // Second byte ... to be defined
  // Third byte ... etc...
    frameDelay=dataReceived[0]*1000;    // First Byte
  } 
  dataToSendCayenne.reset();
}


void  getWeightscale1(void){
  // Get Temperature
  /* Write here your code to get the temperature */
 // units = (scale.get_units(10), 2);
  // Update data to send
  sensors.requestTemperatures(); // Send the command to get temperatures
  float tempC = sensors.getTempCByIndex(0);
    scale1.power_up();
 float poids1 = ((scale1.get_units()*(1-(0.00285*(tempC-25))))-3.35);

 float poids_raw1 = (scale1.get_units()-3.35);
 
 
  dataToSendCayenne.addAnalogInput(1, poids_raw1);
  dataToSendCayenne.addAnalogInput(3, poids1);
  dataToSendCayenne.addTemperature(4, tempC);
  //(scale.get_units(10), 1)
  
  
  scale1.power_down();
}

void  getWeightscale2(void){
  // Get Temperature
  /* Write here your code to get the temperature */
 // units = (scale.get_units(10), 2);
  // Update data to send
 // sensors.requestTemperatures(); // Send the command to get temperatures
 // float tempC = sensors.getTempCByIndex(0);
 
    scale2.power_up();
  float poids_raw2 = (scale2.get_units()-4.84);
 
 
  dataToSendCayenne.addAnalogInput(2, poids_raw2);  
  
  scale2.power_down();
}

void  getWeightscale3(void){
  // Get Temperature
  /* Write here your code to get the temperature */
 // units = (scale.get_units(10), 2);
  // Update data to send
 // sensors.requestTemperatures(); // Send the command to get temperatures
 // float tempC = sensors.getTempCByIndex(0);
 
    scale3.power_up();
  float poids_raw3 = (scale3.get_units()-4.84);
 
 
  dataToSendCayenne.addAnalogInput(5, poids_raw3);  
  
  scale3.power_down();
}

/*void getWeight(void){
  // Get Weight
  /* Write here your code to get the weight */
/*  // Update data to send 
  dataToSendCayenne.addAnalogOutput(1, 75.45f);  
}
*/
void enterLowPower(void){
  Serial.print(" Processor goes in Low Power mode during : ");
  Serial.print(frameDelay);Serial.println("ms\r\n");
  Serial.print(" Using the Low Power features usually corrupts the Serial Link ");
  LowPower.deepSleep(frameDelay); 
  Serial.println(" Wake Up !!!");  
}

void wait(void){
  Serial.print(" Processor is going to wait during : ");
  Serial.print(frameDelay);Serial.println("ms\r\n");
  delay(frameDelay); 
}

void DS18B20_1(void){   

sensors.requestTemperatures(); // Send the command to get temperatures
  float tempC = sensors.getTempCByIndex(0);
if(tempC != DEVICE_DISCONNECTED_C) 
  {
    Serial.print("Temperature for the device 1 (index 0) is: ");
    Serial.println(tempC);
    dataToSendCayenne.addTemperature(4, tempC);
  } 
  else
  {
    Serial.println("Error: Could not read temperature data");
  }
   }

 void Max17048(void){

 // lipo.getSOC() returns the estimated state of charge (e.g. 79%)
  soc = lipo.getSOC(); 

  dataToSendCayenne.addAnalogInput(6, soc);
    
 }

void SHT4x(void){
  
uint16_t error;
    char errorMessage[256];

    delay(1000);

    float temperatureshtx;
    float humidityshtx;
    error = sht4x.measureHighPrecision(temperatureshtx, humidityshtx);
    if (error) {
        Serial.print("Error trying to execute measureHighPrecision(): ");
        errorToString(error, errorMessage, 256);
        Serial.println(errorMessage);
    } else {
        Serial.print("Temperature:");
        Serial.print(temperatureshtx);
        Serial.print("\t");
        Serial.print("Humidity:");
        Serial.println(humidityshtx);

dataToSendCayenne.addTemperature(7, temperatureshtx);
dataToSendCayenne.addRelativeHumidity(8, humidityshtx);        
    }  
}

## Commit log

2022-06-07 First commit V0.2
    [1050170001.stp, 12BHC186P1-GR.stp, 1546215-2.stp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]
2022-06-07 Added HX711
    [ruche-B_Cu.gbl, ruche-B_Mask.gbs, ruche-B_Paste.gbp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]
2022-06-08 design updated
    [ruche.kicad_pcb, ruche.kicad_sch]
2022-06-22 Ajouté code
    [ruche-B_Cu.gbl, ruche-B_Mask.gbs, ruche-B_Paste.gbp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]
2022-07-24 séchoir
    [ruche.csv]
2022-12-03 Modification câblage SHT41 sur multiplexeur TCA9548APWR Mise à jour de plans de la balance et fichiers STL
    [1050170001.stp, 12BHC186P1-GR.stp, 1546215-2.stp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]
